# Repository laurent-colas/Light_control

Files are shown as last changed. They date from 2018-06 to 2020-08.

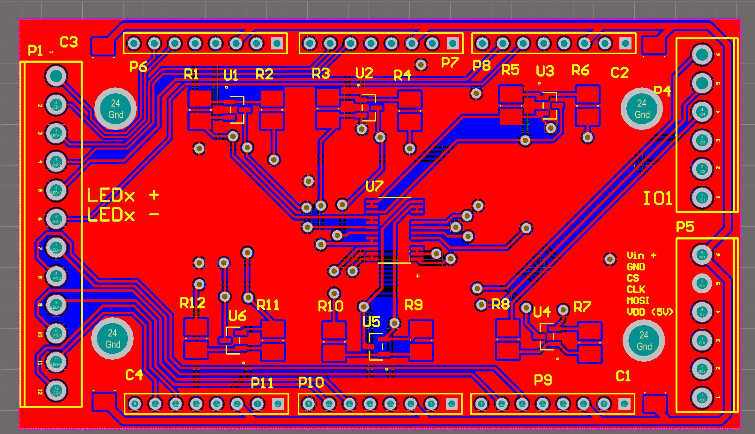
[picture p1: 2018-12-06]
CAD/LED driver buckpuck/Lumiere_ctrl_altiumV3/Img_pcb_annote.JPG

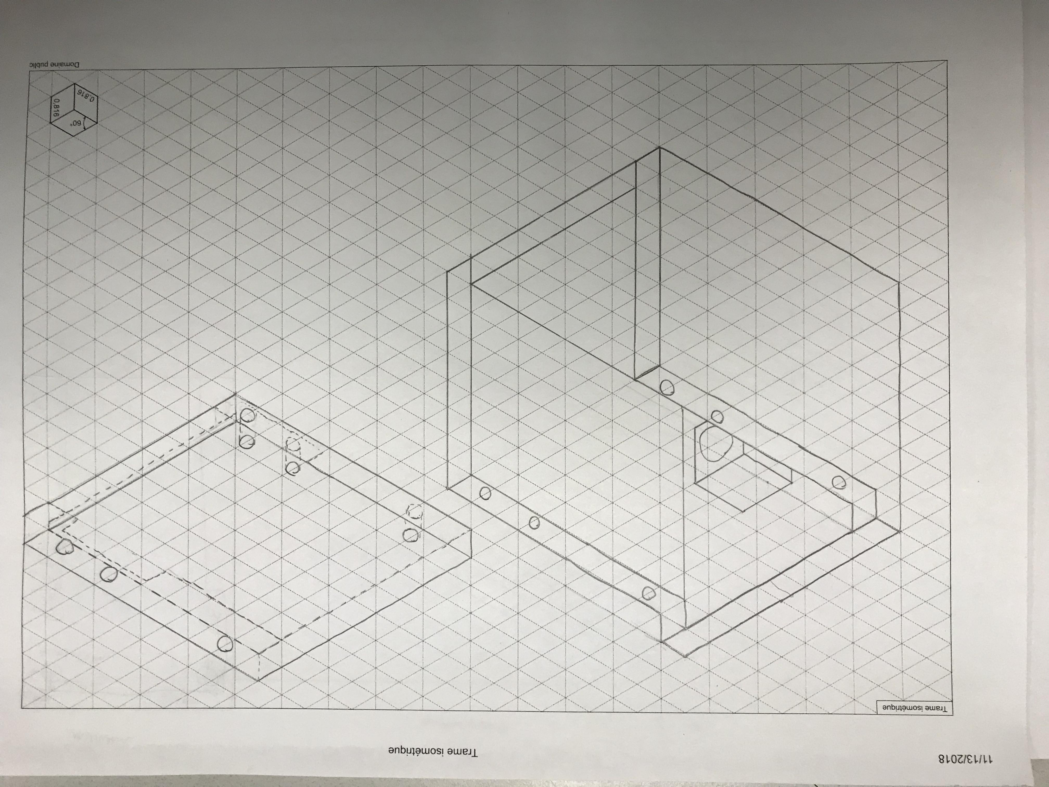
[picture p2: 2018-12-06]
CAD/Motion Detector/Detector Case/Detector V2/ISO_boitier.jpg

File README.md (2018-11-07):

# Light_control
Flask application for controlling lights in my house. 
This includes ESP8266 and ESP32 firmware for motion detectors, On-Off switches, On-Off Buttons. It also includes flask application to physically control light state / brightness with a 16 channel pwm controller, create macros to bundle rooms together and control these rooms with a simple click and check state online of every light.

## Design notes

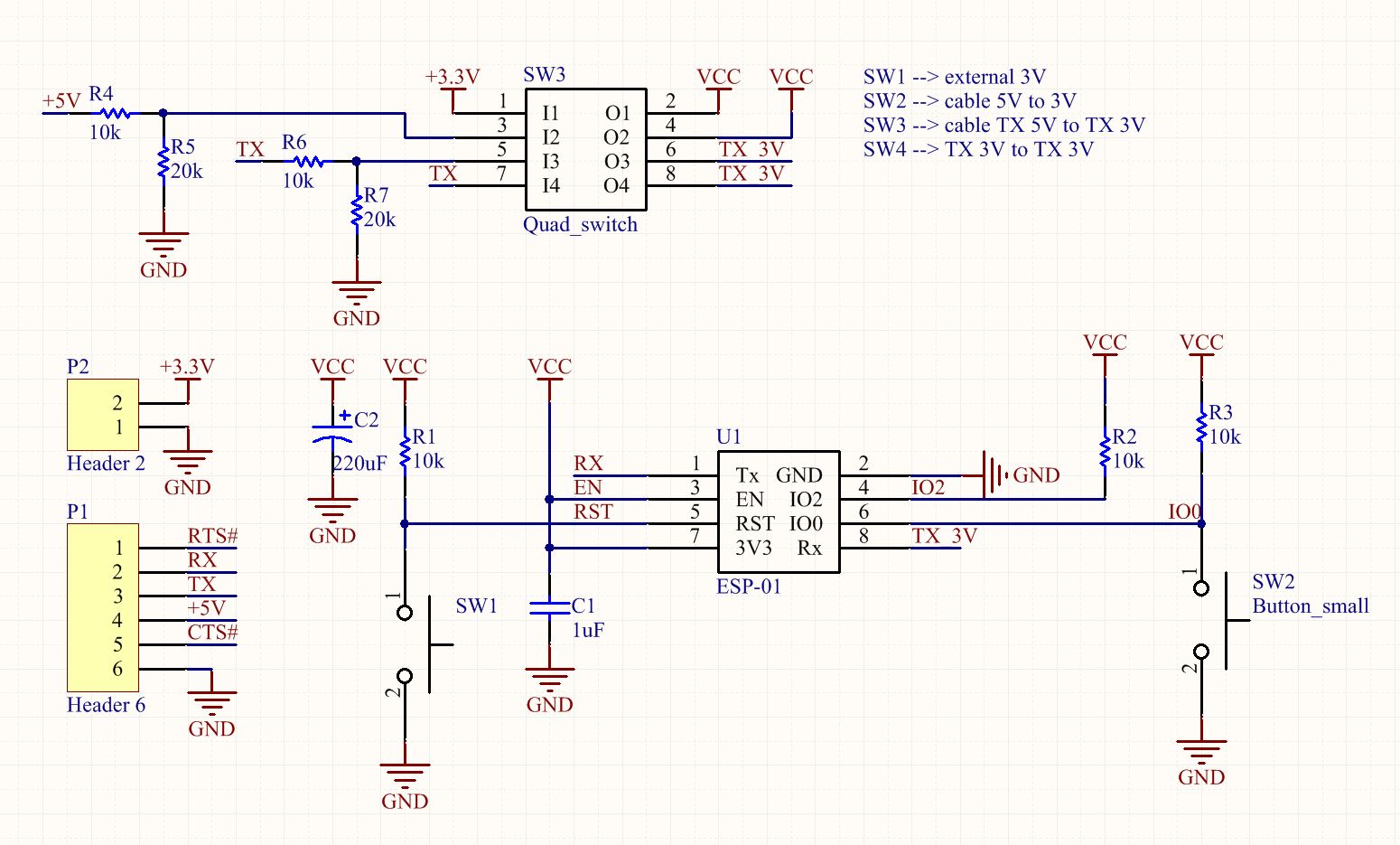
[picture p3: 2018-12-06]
CAD/Motion Detector/MotionDetectorV2/Images/Flashing_Circuit_Schematic_V2.jpg

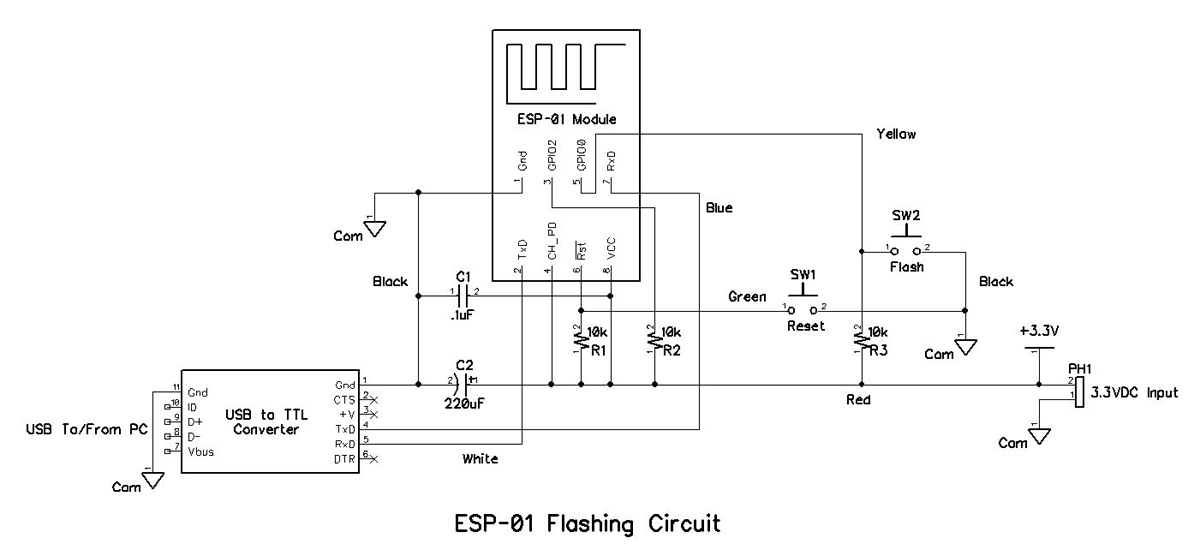
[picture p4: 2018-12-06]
CAD/Motion Detector/MotionDetectorV2/Images/Flashing_Circuit_Schematic.jpg

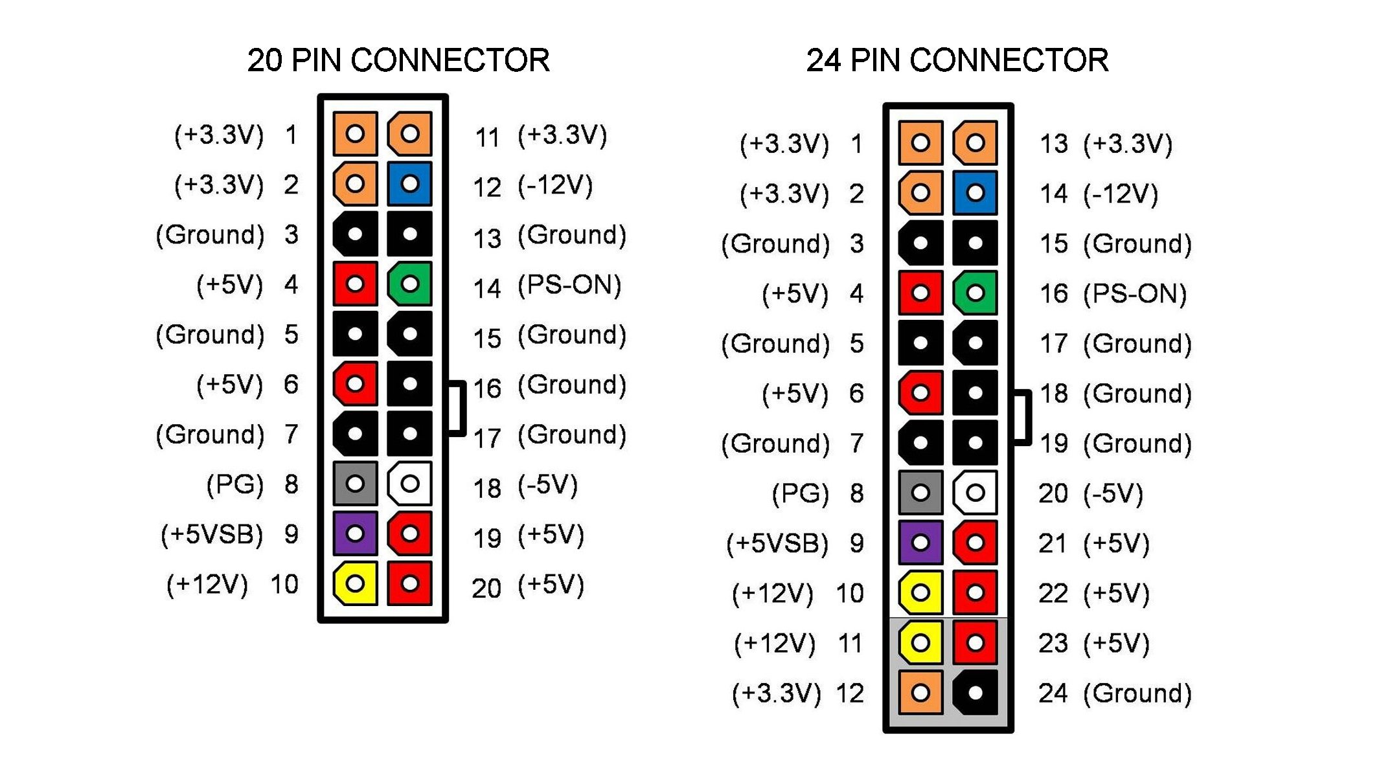
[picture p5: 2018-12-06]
Documentation/pinout_PSU.jpg

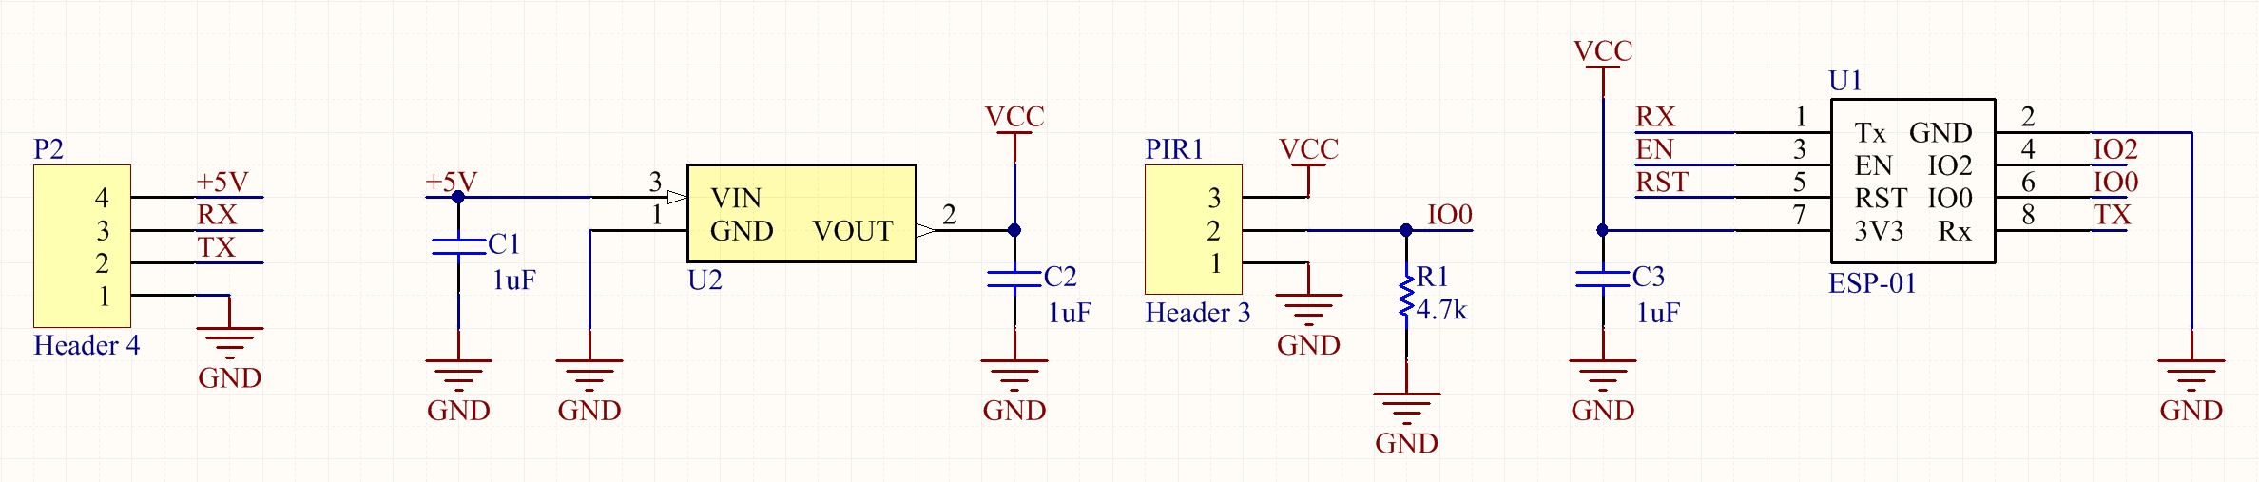
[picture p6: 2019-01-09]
CAD/Motion Detector/MotionDetectorV2/Schematic_MotionDetectV1.JPG

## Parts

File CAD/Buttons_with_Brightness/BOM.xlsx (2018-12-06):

Index | Quantity | Part Number | Manufacturer Part Number | Description | Customer Reference | Available | Backorder | Unit Price | Extended Price CAD
2 | 1 | P470ACT-ND | ERJ-6GEYJ471V | RES SMD 470 OHM 5% 1/8W 0805 |  | 1 | 0 | 0.15 | 0.15
4 | 1 | 401-1978-ND | D6R90 F1 LFS | SWITCH PUSH SPST-NO 0.1A 32V |  | 1 | 0 | 1.36 | 1.36
9 | 1 | 987-1277-ND | P090S-14T20BR10K | POT 10K OHM 1/32W PLASTIC LINEAR |  | 1 | 0 | 1.02 | 1.02
10 | 1 | 987-1276-ND | P090S-04F20BR10K | POT 10K OHM 1/32W PLASTIC LINEAR |  | 1 | 0 | 1.02 | 1.02
11 | 1 | 226-4092-ND | OEJL-50-4-7 | KNOB KNURLED 0.236" METAL |  | 1 | 0 | 9.71 | 9.71
15 | 1 | P10KDACT-ND | ERA-6AEB103V | RES SMD 10K OHM 0.1% 1/8W 0805 |  | 1 | 0 | 0.54 | 0.54
16 | 1 | PTA2043-2015DPB103-ND | PTA2043-2015DPB103 | SLIDE POT 10K OHM 0.1W TOP 20MM |  | 1 | 0 | 1.83 | 1.83

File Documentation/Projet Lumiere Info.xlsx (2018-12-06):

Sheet: Naming Shematic
IO # | Name | Nom de la zone |  | Nombre de LED par zone | Endroit dimable | Sur page principale | Pre set 1 | Pre set 2
22 | RELAY1 | Entrée |  | 4 |  | x | x
23 | RELAY2 | Garde Robe entrée |  | 2 |  | x | x
24 | RELAY3 | Corridor |  | 4 | x | x | x
25 | RELAY4 | Salon |  | 3 | x | x | x
26 | RELAY5 | Cuisine | Drop Down | 4 | x | x | x
27 | RELAY6 | Comptoir telephone cuisine |  | 2 |  |  | x
28 | RELAY7 | Comptoir lavabos cuisine |  | 2 |  |  | x
29 | RELAY8 | Salle à manger |  | 3 | x
30 | RELAY9 | Fond salle à manger |  | 3 | x
31 | RELAY10 | Salle d'ordinateur |  | 1 |  |  | x
32 | RELAY11 | Salle de Bain 1er étage |  | 2 | x |  | x
33 | RELAY12 | Chambre d'invité Télé |  | 2
34 | RELAY13 | Chambre d'invité Lit |  | 4 | x
35 | RELAY14 | Chambre d'invité garde-Robe |  | 2
36 | RELAY15 | Chambre d'invité imprimante |  | 1
37 | RELAY16 | Bibliothèque |  | 3
38 | RELAY17 | Escalier Sous-sol |  | 3
39 | RELAY18 | Plafond escalier sous-sol |  | 3
40 | RELAY19 | Sous-Sol |  | 6 | x
41 | RELAY20 | Fond sous-sol |  | 3
42 | RELAY21 | Chambre Laurent |  | 3 | x
43 | RELAY22 | Garde Robe Laurent |  | 1
44 | RELAY23 | Chambre Anne-Sophie |  | 2 | x
45 | RELAY24 | Walk-in Anne-Sophie |  | 1
46 | RELAY25 | Rangement Anne-Sophie |  | 2
47 | RELAY26 | Salle de lavage |  | 2
48 | RELAY27 | Salle de Bain 2ième étage |  | 3 | x
49 | RELAY28 | Statue |  | 1
50 | RELAY29 | Chambre parents lits |  | 2 | x
51 | RELAY30 | Chambre parents fenêtre |  | 2 | x
52 | RELAY31 | Walk-in parents |  | 2
53 | RELAY32 | Rangement parents |  | 2
 |  | Nombre de DEL total |  | 80 | 13

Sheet: RC
IO # | Name | Nom de la zone | Nombre de LED par zone | Endroit dimable | Sur page principale | Pre set 1 | Pre set 2
22 | RELAY1 | Entrée | 4
23 | RELAY2 | Garde Robe entrée | 2
24 | RELAY3 | Corridor | 4
25 | RELAY4 | Salon | 3
26 | RELAY5 | Cuisine | 6
27 | RELAY6 | Comptoir telephone cuisine | 1
28 | RELAY7 | Comptoir lavabos cuisine | 4
29 | RELAY8 | Salle à manger | 3
30 | RELAY9 | Fond salle à manger | 2
31 | RELAY10 | Salle d'ordinateur | 1
32 | RELAY11 | Salle de Bain 1er étage | 6
33 | RELAY12 | Chambre d'invité Télé | 2
34 | RELAY13 | Chambre d'invité Lit | 4
35 | RELAY14 | Chambre d'invité garde-Robe | 2
36 | RELAY15 | Chambre d'invité imprimante | 1
37 | RELAY16 | Bibliothèque | 2

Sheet: LED Driver board specs
Pour | 1
 | Index | Quantity per board | Part Number | Manufacturer Part Number | Description | Unit Price | Extended Price per board
 | 1 | 6 | MMBT3906LT1GOSCT-ND | MMBT3906LT1G | TRANS PNP 40V 0.2A SOT23 | 0.146 | 0.876
 | 2 | 12 | YAG5090CT-ND | RT1206BRD075KL | RES SMD 5K OHM 0.1% 1/4W 1206 | 0.3012 | 3.6144
 | 3 | 4 | 1276-1053-1-ND | CL31C101JBCNNNC | CAP CER 100PF 50V C0G/NP0 1206 | 0.15 | 0.6
 | 4 | 1 | AD5206BRUZ10-RL7CT-ND | AD5206BRUZ10-RL7 | IC POT DGTL 6CH 256POS 24-TSSOP | 8.54 | 8.54
 | 5 | 12 | 277-1721-ND | 1984617 | CONN TERM BLOCK T/H 2POS 3.5MM | 0.565 | 6.78
 | 6 | 6 | S7041-ND | PPPC081LFBN-RC | CONN HEADER FEMALE 8POS .1" GOLD | 0.863 | 5.178
 |  |  |  |  |  | Subtotal | 25.5884
Pour | 6
 |  | Quantity | Unfinished boards | Description | Manufacturer Part Number | Total | Extended Price
 |  | 36 | 0 | TRANS PNP 40V 0.2A SOT23 | MMBT3906LT1G | 36 | 5.256
 |  | 72 | 0 | RES SMD 5K OHM 0.1% 1/4W 1206 | RT1206BRD075KL | 72 | 21.6864
 |  | 24 | 8 | CAP CER 100PF 50V C0G/NP0 1206 | CL31C101JBCNNNC | 32 | 4.8
 |  | 6 | 4 | IC POT DGTL 6CH 256POS 24-TSSOP | AD5206BRUZ10-RL7 | 10 | 85.4
 |  | 72 | 42 | CONN TERM BLOCK T/H 2POS 3.5MM | 1984617 | 114 | 64.41
 |  | 36 | 24 | CONN HEADER FEMALE 8POS .1" GOLD | PPPC081LFBN-RC | 60 | 51.78
 |  |  |  |  |  | Subtotal | 233.3324

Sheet: Orders
Supplier | Index | Quantity | Part Number | Manufacturer Part Number | Description | Unit Price | Extended Price | Shipping
Digikey | 1 | 2 | 976-1396-ND | BXRC-30E1000-D-73 | LED COB VERO 10 3000K STARBOARD | 4.32 $ | 8.64 $ | 0.00 $
 | 2 | 1 | 976-1254-ND | BXRC-30E2000-C-23 | LED ARRAY 2000LM WARM WHITE COB | 7.83 $ | 7.83 $
 | 3 | 1 | 976-1242-ND | BXRC-27E4000-F-23 | LED ARRAY 4000LM WARM WHITE COB | 14.35 $ | 14.35 $
 | 4 | 100 | YAG5090CT-ND | RT1206BRD075KL | RES SMD 5K OHM 0.1% 1/4W 1206 | 0.29 $ | 29.42 $
 | 5 | 100 | 1276-1053-1-ND | CL31C101JBCNNNC | CAP CER 100PF 50V C0G/NP0 1206 | 0.07 $ | 6.91 $
 | 6 | 60 | S7041-ND | PPPC081LFBN-RC | CONN HEADER FEMALE 8POS .1" GOLD | 0.84 $ | 50.58 $
 | 7 | 40 | 277-1724-ND | 1984659 | CONN TERM BLOCK T/H 6POS 3.5MM | 1.64 $ | 65.76 $
 | 8 | 100 | MMBTA92LT1GOSCT-ND | MMBTA92LT1G | TRANS PNP 300V 0.5A SOT23 | 0.14 $ | 13.93 $
 | 9 | 40 | MMBT3906LT1GOSCT-ND | MMBT3906LT1G | TRANS PNP 40V 0.2A SOT23 | 0.15 $ | 5.84 $ | 0.00 $
 | 10 | 100 | YAG5090CT-ND | RT1206BRD075KL | RES SMD 5K OHM 0.1% 1/4W 1206 | 0.30 $ | 30.12 $
 | 11 | 10 | 1276-1053-1-ND | CL31C101JBCNNNC | CAP CER 100PF 50V C0G/NP0 1206 | 0.15 $ | 1.50 $
 | 12 | 6 | AD5206BRUZ10-RL7CT-ND | AD5206BRUZ10-RL7 | IC POT DGTL 6CH 256POS 24-TSSOP | 8.54 $ | 51.24 $
 | 13 | 10 | 277-1721-ND | 1984617 | CONN TERM BLOCK T/H 2POS 3.5MM | 0.56 $ | 5.65 $
 | 14 | 10 | 277-1578-ND | 1935174 | TERM BLOCK PCB 3POS 5.0MM GREEN | 0.72 $ | 7.23 $
 | 15 | 10 | 277-1581-ND | 1935200 | TERM BLOCK PCB 6POS 5.0MM GREEN | 1.46 $ | 14.57 $
 | 16 | 10 | 277-1587-ND | 1935268 | TERM BLOCK PCB 12POS 5.0MM GREEN | 2.78 $ | 27.77 $
 | 17 | 40 | S7041-ND | PPPC081LFBN-RC | CONN HEADER FEMALE 8POS .1" GOLD | 0.86 $ | 34.52 $
Amazon | 18 | 4 | LED-277 | B01CS5G8J6 | NEWSTYLE 24V 15A Dc Universal Regulated Switching Power Supply 360W | 33.98 $ | 135.92 $ | 21.52 $
 | 19 | 2 | 101-70-103 | B0057OC66U | SainSmart 16-Channel Relay Module | 23.99 $ | 47.98 $ | 0.00 $
 | 20 | 1 | NCUIABVYA0225 | B01CCF6V3A | CanaKit Raspberry Pi 3 Complete Starter Kit - 32 GB Edition | 99.99 $ | 99.99 $
McMaster-Carr | 21 | 10 | 98952A108 |  | Aluminum Male-Female Threaded Hex Standoff, 4.5mm Hex, 10mm Long, M3 x 0.50 mm Thread | 1.35 $ | 13.50 $ | 12.89 $
 | 22 | 10 | 98952A102 |  | Aluminum Male-Female Threaded Hex Standoff, 4.5mm Hex, 5mm Long, M3 x 0.50 mm | 1.29 $ | 12.90 $
 | 23 | 10 | 98952A112 |  | Aluminum Male-Female Threaded Hex Standoff, 4.5mm Hex, 14mm Long, M3 x 0.50 mm | 1.40 $ | 14.00 $
 | 24 | 10 | 98952A118 |  | Aluminum Male-Female Threaded Hex Standoff, 4.5mm Hex, 20mm Long, M3 x 0.50 mm | 1.47 $ | 14.70 $
 | 25 | 1 | 92000A118 |  | Passivated 18-8 Stainless Steel Pan Head Phillips Screws, M3 x 0.5mm Thread, 8mm Long | 4.16 $ | 4.16 $
 | 26 | 1 | 92000A114 |  | Passivated 18-8 Stainless Steel Pan Head Phillips Screws, M3 x 0.5mm Thread, 5mm Long | 4.12 $ | 4.12 $
 | 27 | 20 | 95947A006 |  | Aluminum Female Threaded Hex Standoff, 4.5mm Hex, 10mm Long, M3 x 0.50 mm Thread | 0.45 $ | 9.00 $
 | 28 | 1 | 93187A100 |  | Brass Thin Hex Nut, M3 x 0.5 mm Thread | 7.59 $ | 7.59 $
 | 29 | 5 |  |  | 300V AC/300V DC Terminal Block, Twelve 20A | 5.45 $ | 27.25 $ | 19.65 $
 | 30 | 5 |  |  | Cover for 12 Circuit 3/8" Center-to-Center 300V AC/300V DC Terminal Block | 3.35 $ | 16.75 $
 | 31 | 2 |  |  | Spade Terminals, Nylon Insulated, Flanged, for 22-18 Gauge & Number 6 Screw, Packs of 50 | 12.05 $ | 24.10 $
 | 32 | 2 |  |  | Spade Terminals, Nylon Insulated, Flanged, for 16-14 Gauge & Number 6 Screw, Packs of 50 | 12.24 $ | 24.48 $
Subtotal | 832.30 $ |  |  |  |  |  |  | 54.06 $
Total | 886.36 $

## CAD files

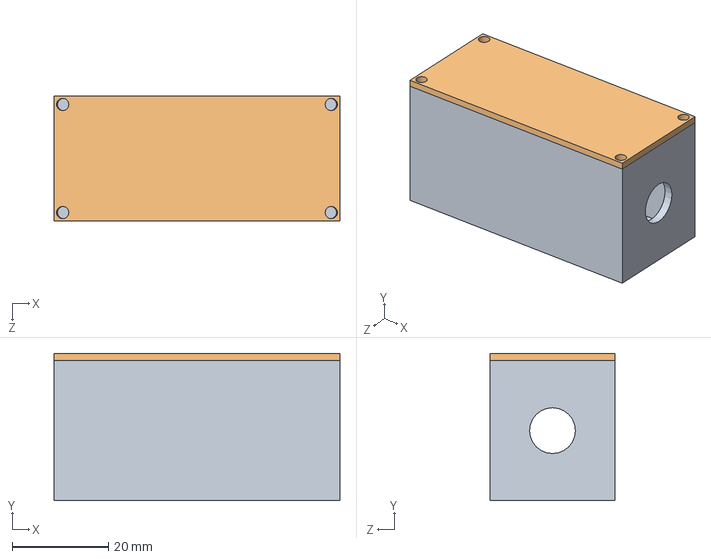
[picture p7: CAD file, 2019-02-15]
CAD/Motion Detector/Detector Case/Detector V2/AssemblyV2.SLDASM
59.3 x 30.5 x 26.0 mm
BDv2
CapuchonV2

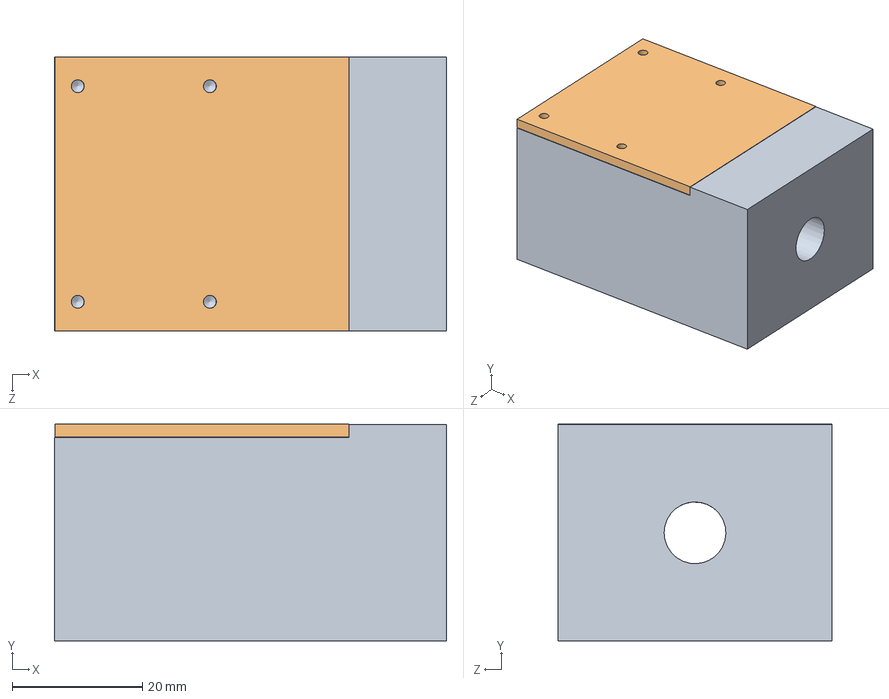
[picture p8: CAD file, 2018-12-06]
CAD/Motion Detector/Detector Case/Detector V2/Assembly detecteur.SLDASM
60.3 x 33.3 x 42.1 mm
boite detecteur
capuchon detecteur

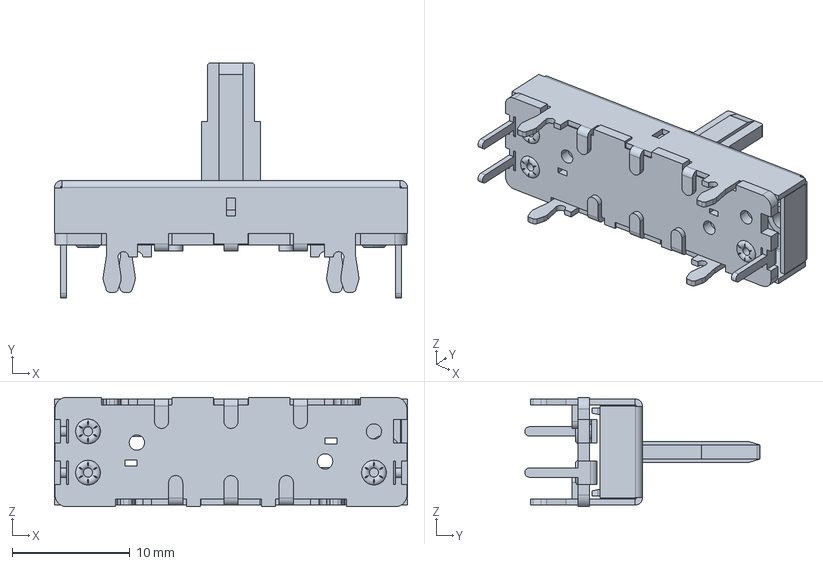
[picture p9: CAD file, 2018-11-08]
CAD/Buttons_with_Brightness/Documentation/Potentiometers/PTA1543-2010CIB103.stp
30.0 x 20.0 x 9.30 mm

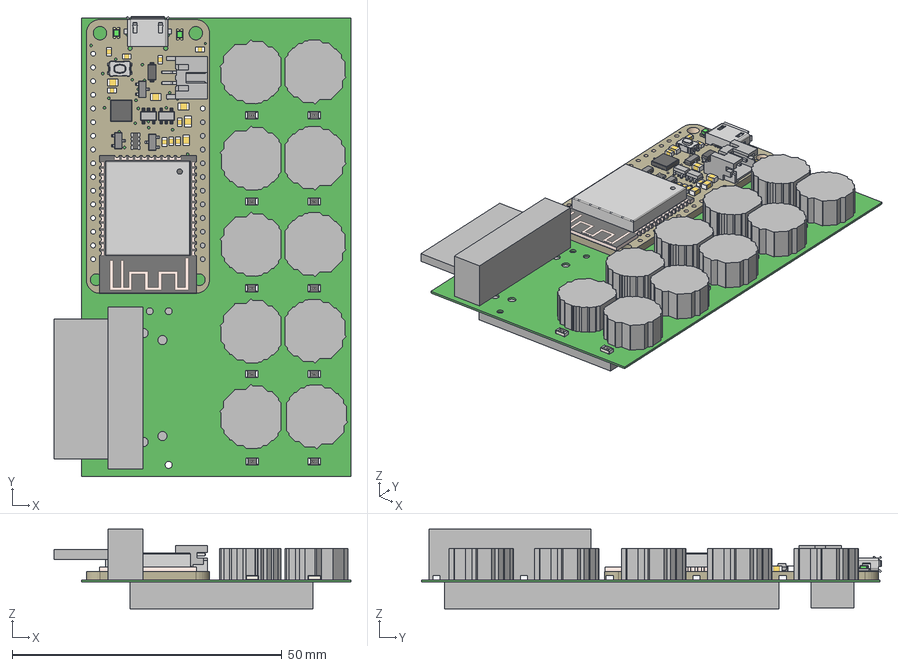
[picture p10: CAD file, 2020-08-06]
CAD/Buttons_with_Brightness/remote_control_light/remote_control_light.step
55.1 x 85.3 x 14.8 mm
Extruded x 14
res0805 x 10
Board
0805-NO x 5
0603-NO x 9
SOT23-5 x 2
SOD-123
JSTPH2
CHIPLED_0805_NOOUTLINE x 2
BTN_KMR2_4.6X2.8
QFN24_4MM_SMSC
4UCONN_20329_V2
SOT23-3 x 2
WROOM32_SKINNY
SOT23-R
RESPACK_4X0603

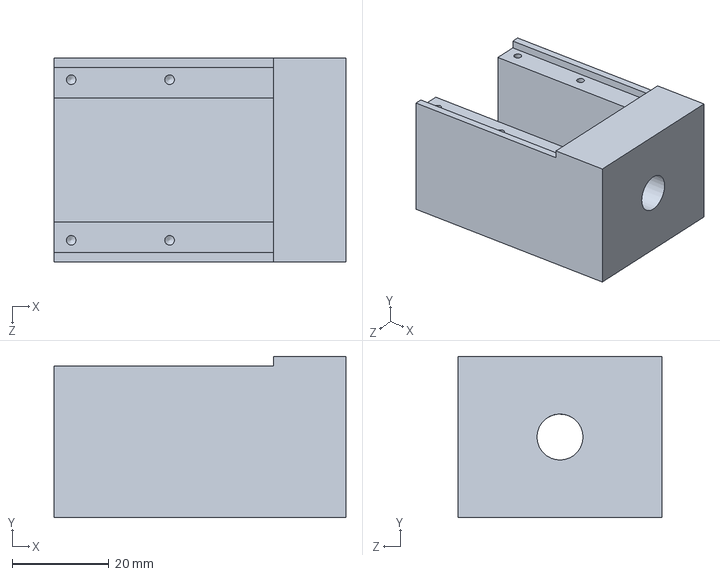
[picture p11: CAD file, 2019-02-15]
CAD/Motion Detector/Detector Case/Detector V2/Boite Detecteur V2.SLDPRT
60.3 x 33.3 x 42.1 mm

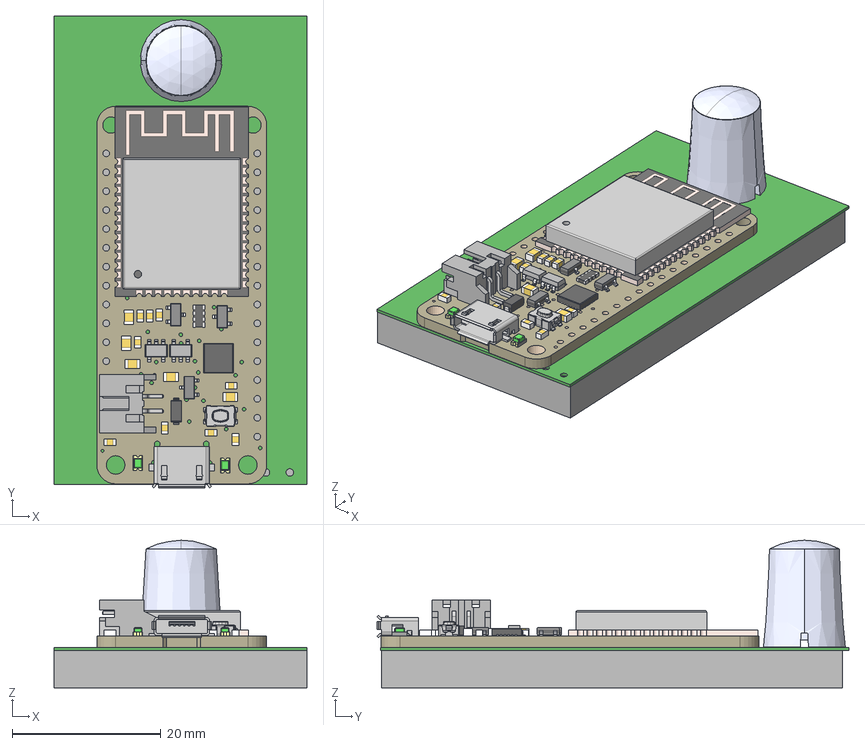
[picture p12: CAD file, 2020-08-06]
CAD/Motion Detector/Motion_detector_ESP32/Motion_detector_ESP32.step
34.0 x 63.5 x 19.9 mm
Extruded
EKM_StandardDetectionType
Board
0805-NO x 5
0603-NO x 9
SOT23-5 x 2
SOD-123
JSTPH2
CHIPLED_0805_NOOUTLINE x 2
BTN_KMR2_4.6X2.8
QFN24_4MM_SMSC
4UCONN_20329_V2
SOT23-3 x 2
WROOM32_SKINNY
SOT23-R
RESPACK_4X0603

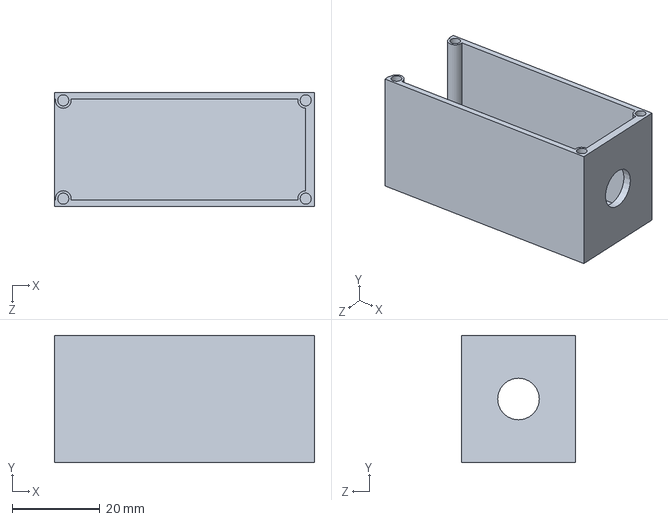
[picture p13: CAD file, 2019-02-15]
CAD/Motion Detector/Detector Case/Detector V2/BDv2.SLDPRT
59.3 x 29.0 x 26.0 mm

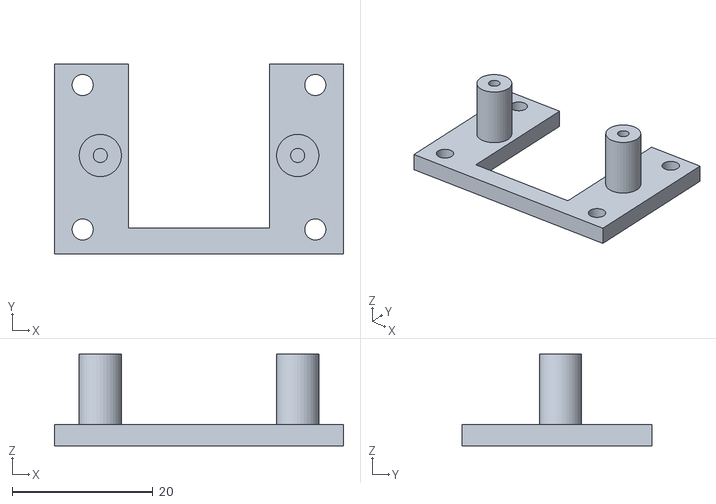
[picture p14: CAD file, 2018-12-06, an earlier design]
CAD/Motion Detector/Detector Case/Detector V1/Detecteur de lumiere interneV2.STL
41.0 x 27.0 x 13.0

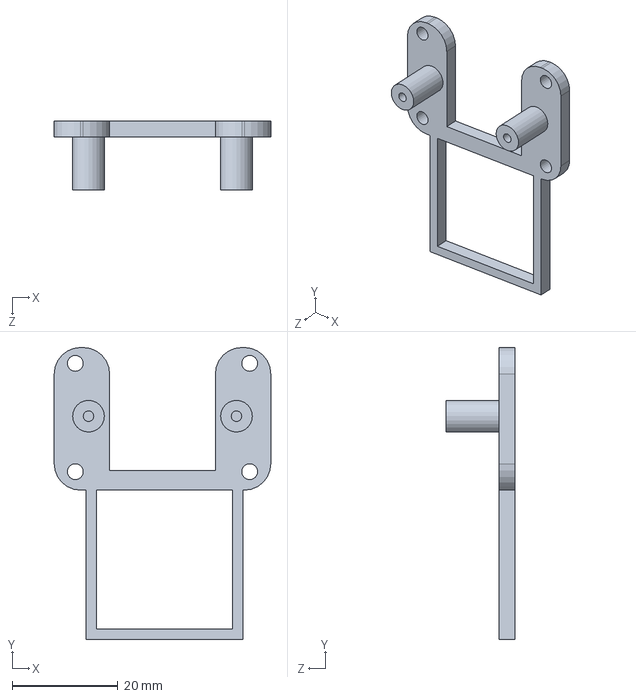
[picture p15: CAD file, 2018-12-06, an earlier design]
CAD/Motion Detector/Detector Case/Detector V1/Detecteur de lumiere interne.SLDPRT
41.0 x 55.3 x 13.0 mm

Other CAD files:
CAD/Motion Detector/Detector Case/Detector V1/Detecteur de lumiere interneV3.STL
CAD/Motion Detector/Detector Case/Detector V1/Detecteur de lumiere interne.STL

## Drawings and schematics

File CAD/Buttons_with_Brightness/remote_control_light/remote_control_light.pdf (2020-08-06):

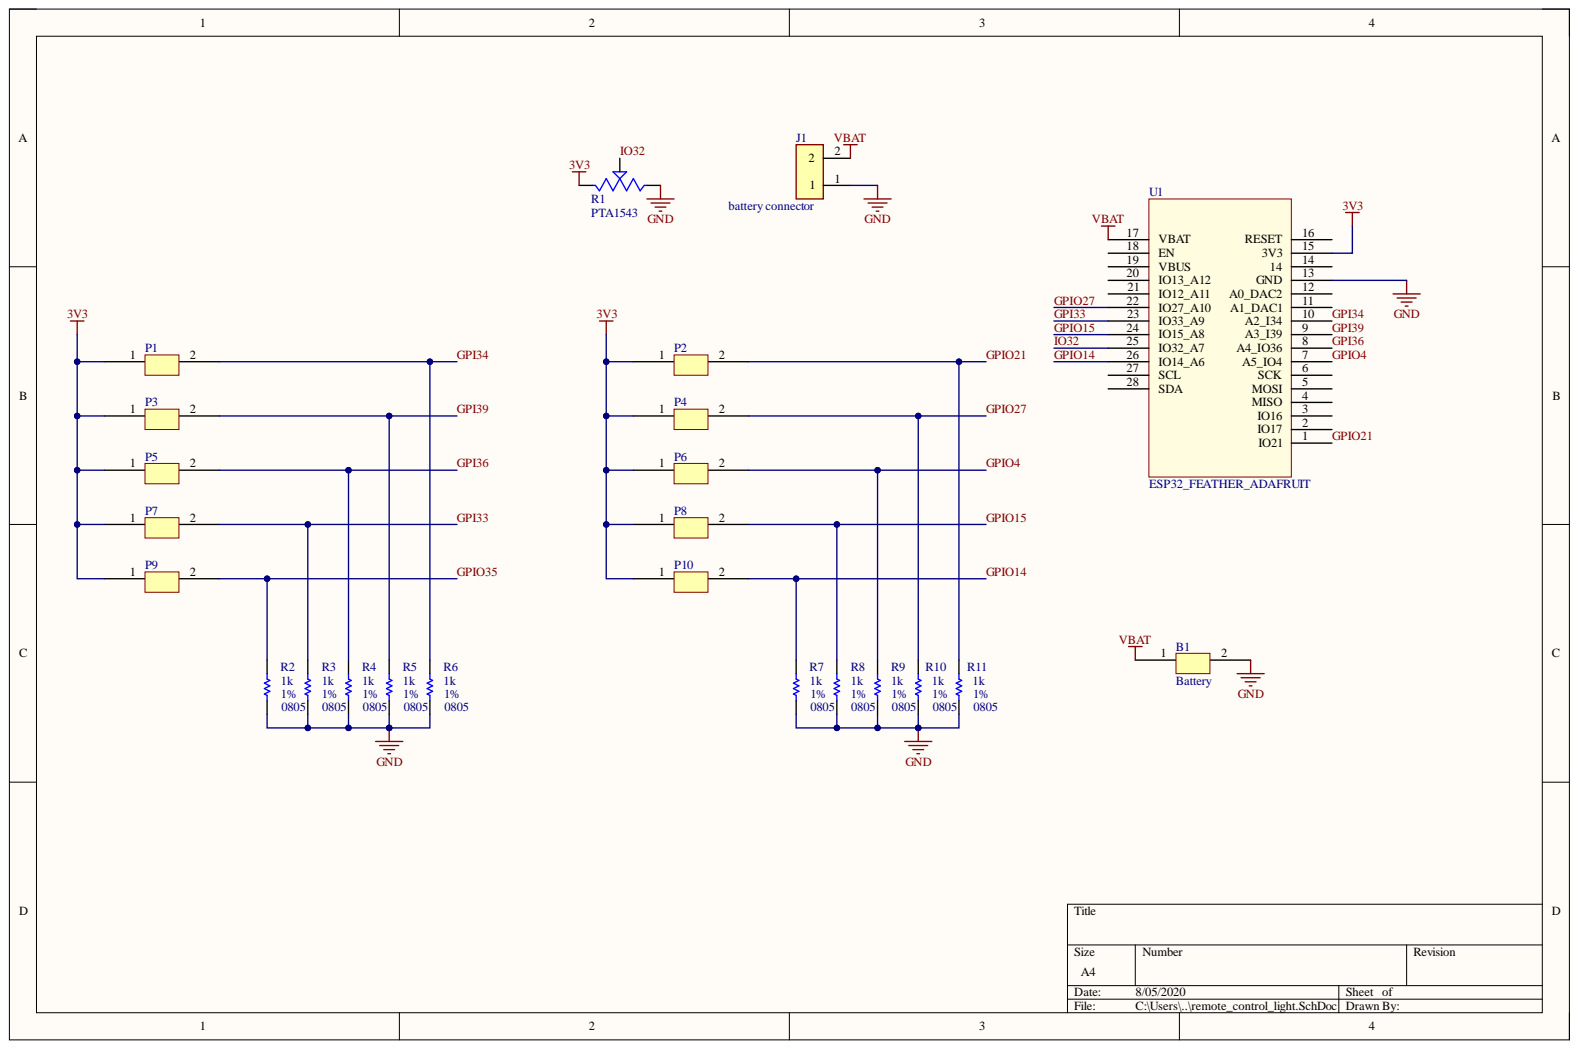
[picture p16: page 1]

Size A4 | Number | Revision

Date: 8/05/2020 | Sheet of
File: C:\Users\..\remote_control_light.SchDoc | Drawn By:

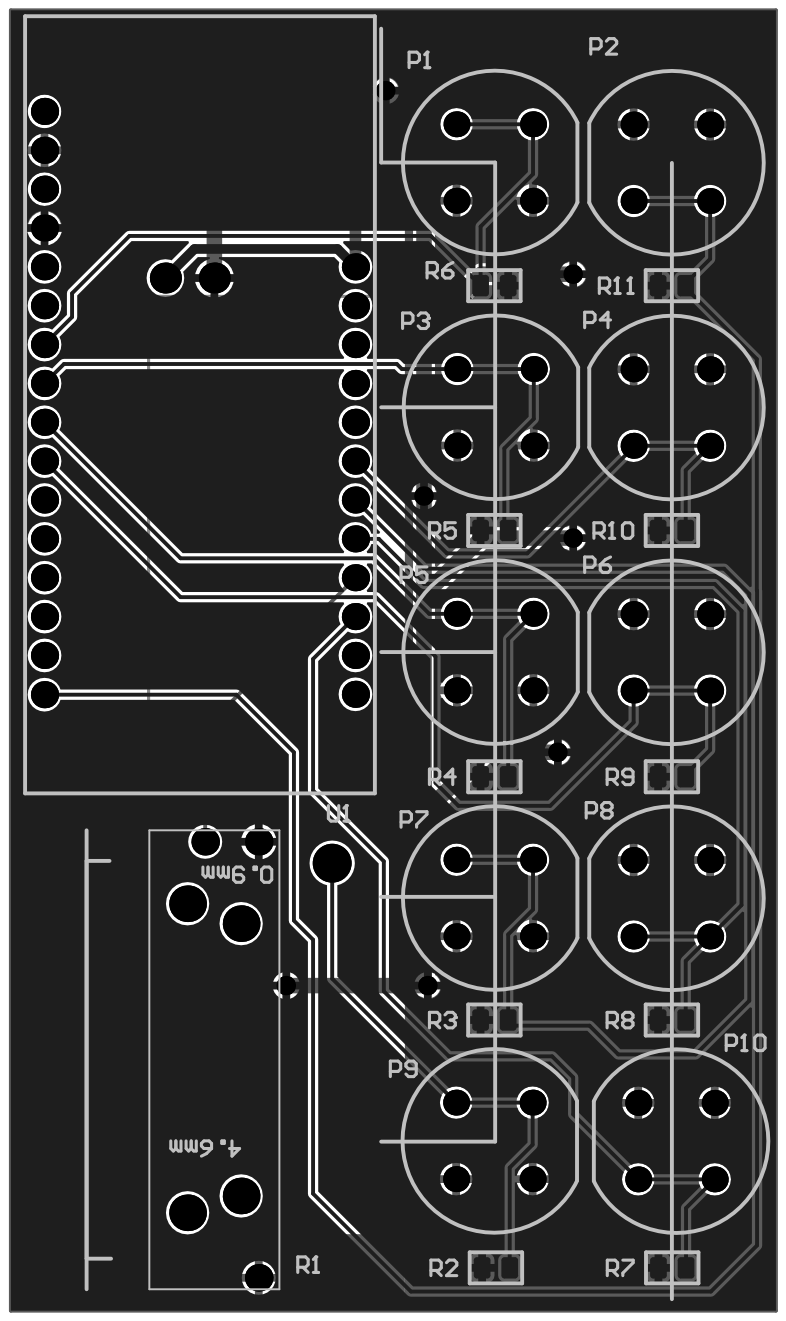
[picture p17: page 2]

Comment | Description | Designator | Footprint | LibRef | Quantity
Battery | | B1 | battery-3.7V-1200mAh | Battery | 1
battery connector | surface mount battery connector | J1 | Battery connector | CONN_BATT | 1
PUSH_BUTTON_D6F | | P1, P2, P3, P4, P5, P6, P7, P8, P9, P10 | PUSH_BUTTON_D6F | PUSH_BUTTON_D6F | 10
PTA1543 | 10 kOhms 0.05W, 1/20W Through Hole Slide Potentiometer Top Adjustment Type | R1 | POT PTA1543 | POT PTA1543 | 1
RES - 0805 | RES - 0805 | R2, R3, R4, R5, R6, R7, R8, R9, R10, R11 | RES_0805 | RES - 0805 | 10
ESP32_FEATHER_ADA FRUIT | | U1 | ESP32_FEATHER | ESP32_FEATHER_ADA FRUIT | 1

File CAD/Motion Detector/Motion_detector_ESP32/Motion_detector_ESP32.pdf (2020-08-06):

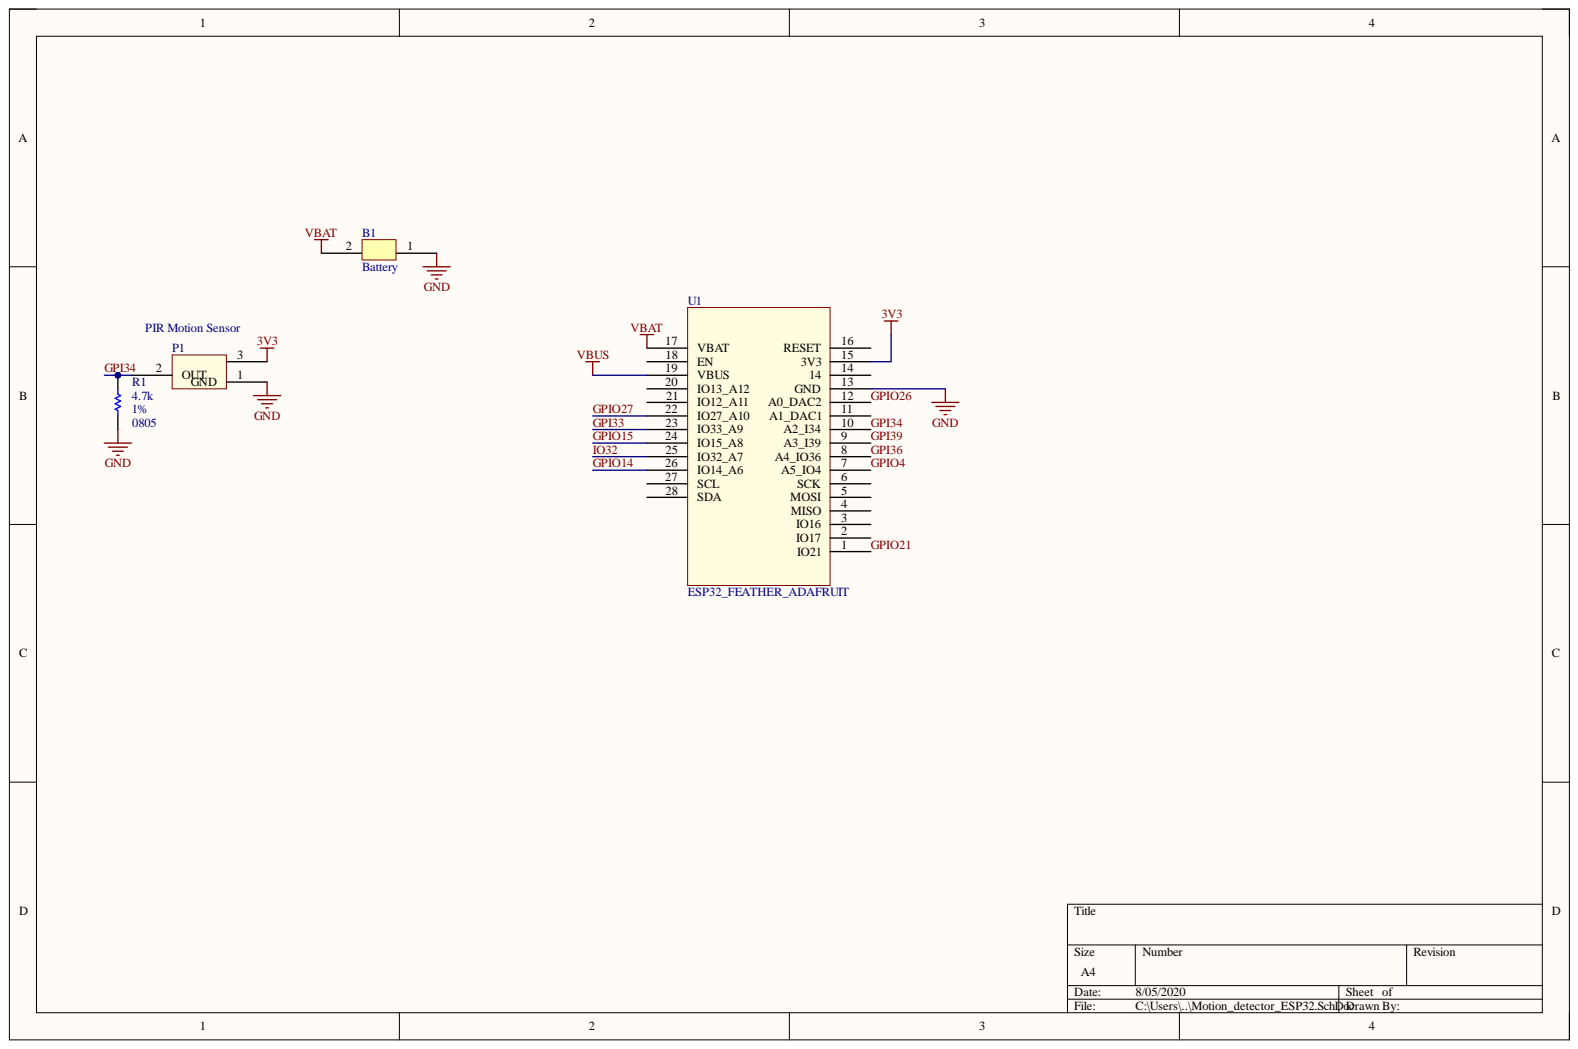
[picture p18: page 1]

Size A4 | Number | Revision

Date: 8/05/2020 | Sheet of
File: C:\Users\..\Motion_detector_ESP32.SchDoDr c awn By:

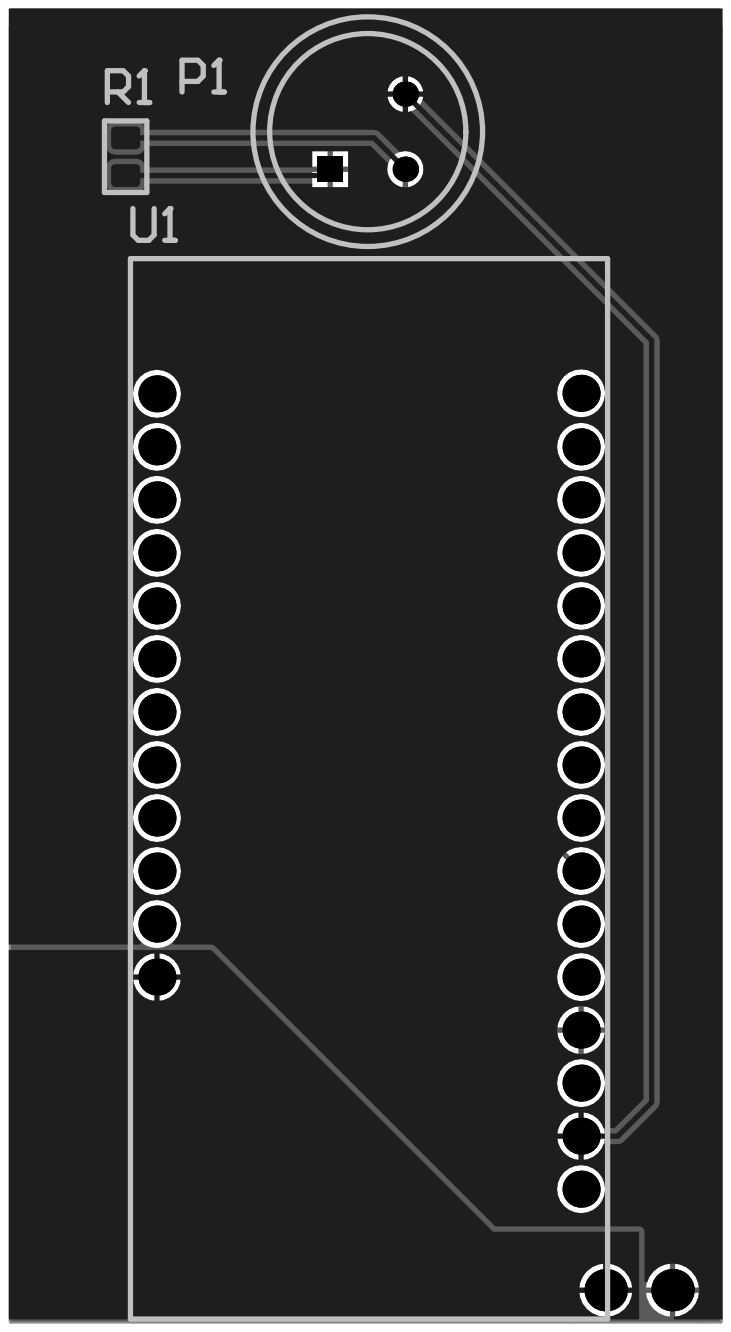
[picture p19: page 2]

Comment | Description | Designator | Footprint | LibRef | Quantity
Battery | | B1 | battery-3.7V-1200mAh | Battery | 1
PIR Motion Sensor | Sensor PIR (Passive Infrared) 197" (5m) 16.4' Polyethylene, White Lens | P1 | EKMB1301111K | PIR Motion Sensor | 1
RES - 0805 | RES - 0805 | R1 | RES_0805 | RES - 0805 | 1
ESP32_FEATHER_ADA FRUIT | | U1 | ESP32_FEATHER | ESP32_FEATHER_ADA FRUIT | 1

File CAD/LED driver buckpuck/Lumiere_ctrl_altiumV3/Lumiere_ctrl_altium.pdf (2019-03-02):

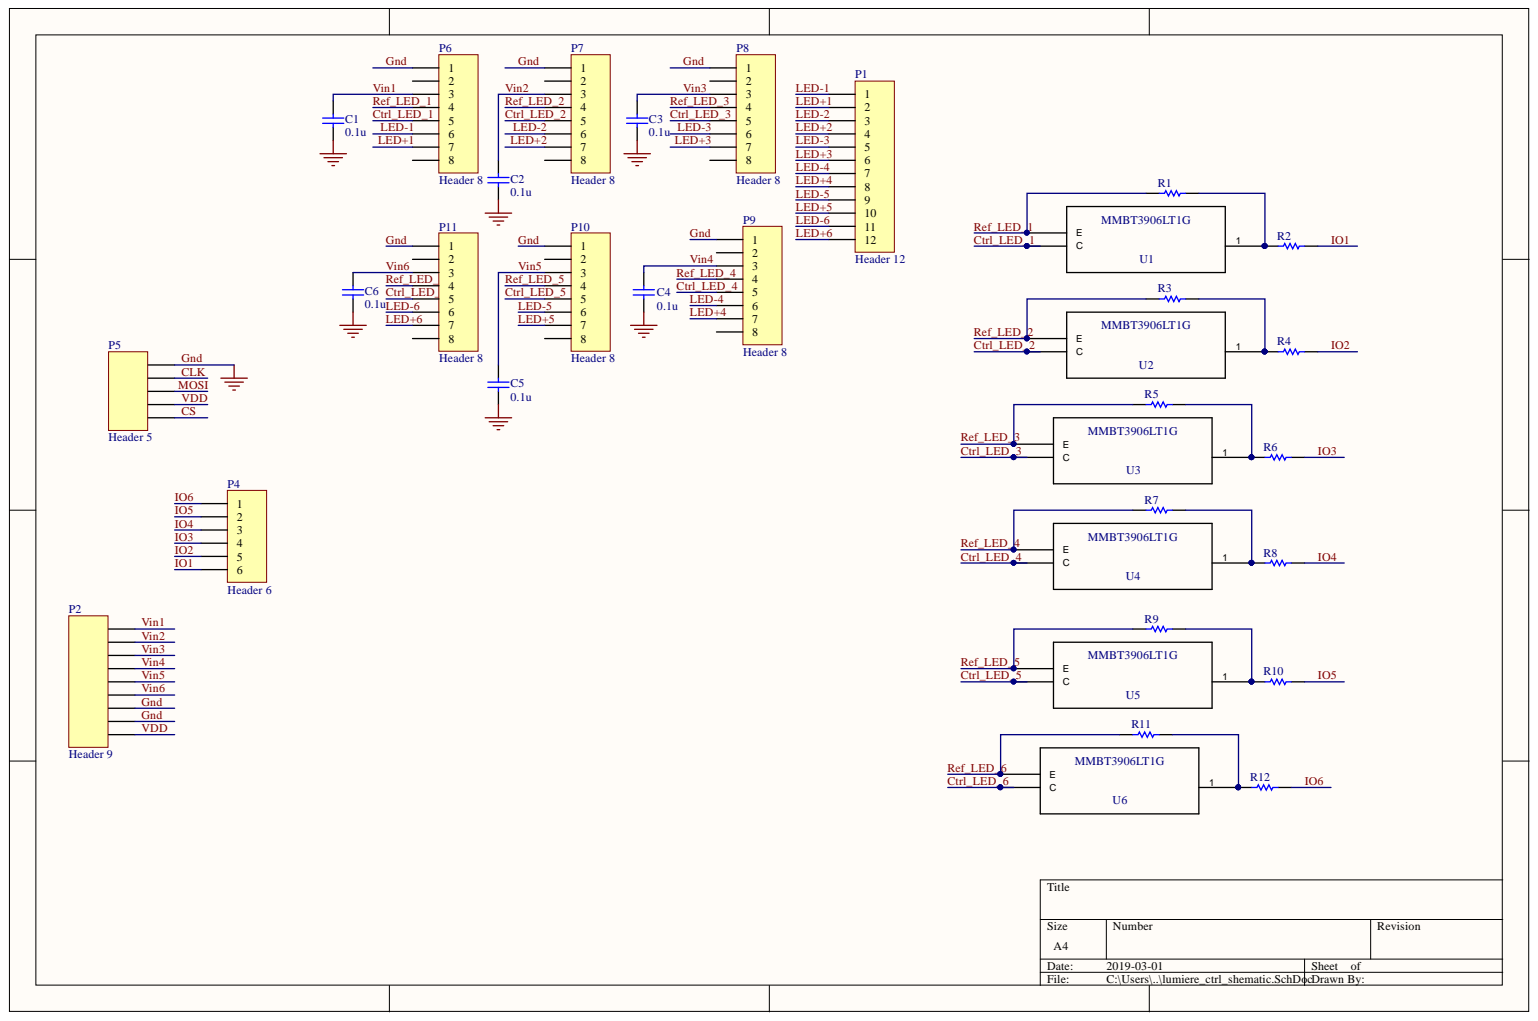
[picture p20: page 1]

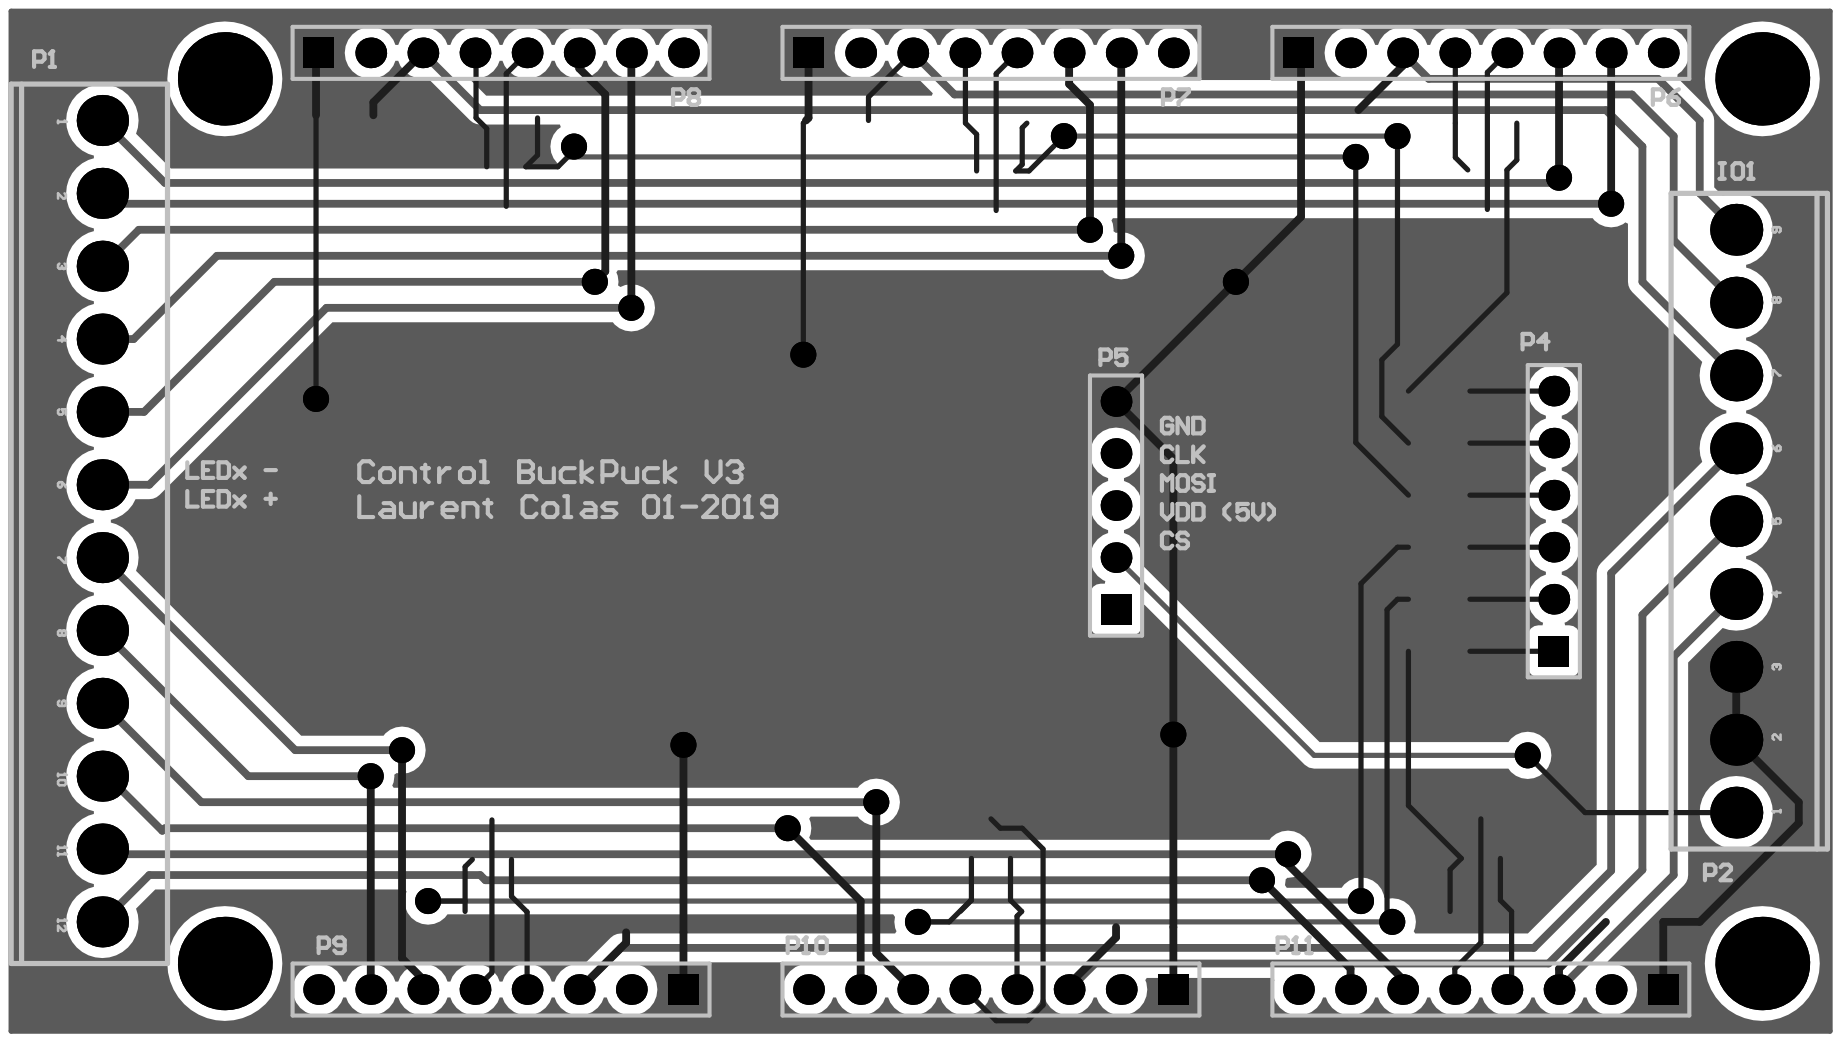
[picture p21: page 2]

Item#C# olumn Name Error:Manufact | #Column Name Error:Manufacturer No | Quantity | #Column Name Error:Note | Designator | Description | Footprint | Comment | LibRef
1 | | 6 | | C1, C2, C3, C4, C5, C6 | Capacitor | CC1206N | CapSMD | CapSMD
2 | | 1 | | P1 | Header, 12-Pin | Terminal block 12 pos | Header 12 | Header 12
3 | | 1 | | P2 | Header, 9-Pin | Terminal block 9 pos | Header 9 | Header 9
4 | | 1 | | P4 | Header, 6-Pin | HDR1X6 | Header 6 | Header 6
5 | | 1 | | P5 | Header, 5-Pin | HDR1X5 | Header 5 | Header 5
6 | | 6 | | P6, P7, P8, P9, P10, P11 | Header, 8-Pin | HDR1X8 | Header 8 | Header 8
7 | | 12 | | R1, R2, R3, R4, R5, R6, R7, R8, R9, R10, R11, R12 | | STA_RMCF1206 | ResSMD | ResSMD
8 | | 6 | | U1, U2, U3, U4, U5, U6 | | SOT-23 | MMBT3906LT1G | MMBT3906LT1G

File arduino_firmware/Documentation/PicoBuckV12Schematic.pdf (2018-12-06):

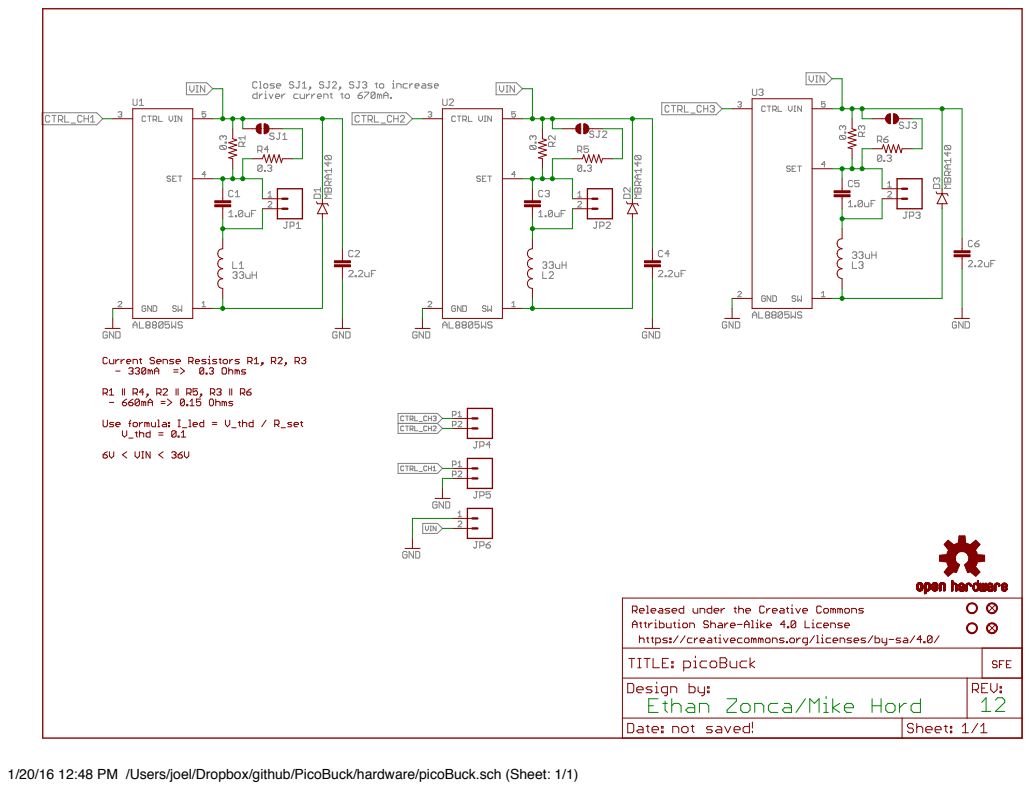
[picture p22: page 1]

1/20/16 12:48 PM /Users/joel/Dropbox/github/PicoBuck/hardware/picoBuck.sch (Sheet: 1/1)

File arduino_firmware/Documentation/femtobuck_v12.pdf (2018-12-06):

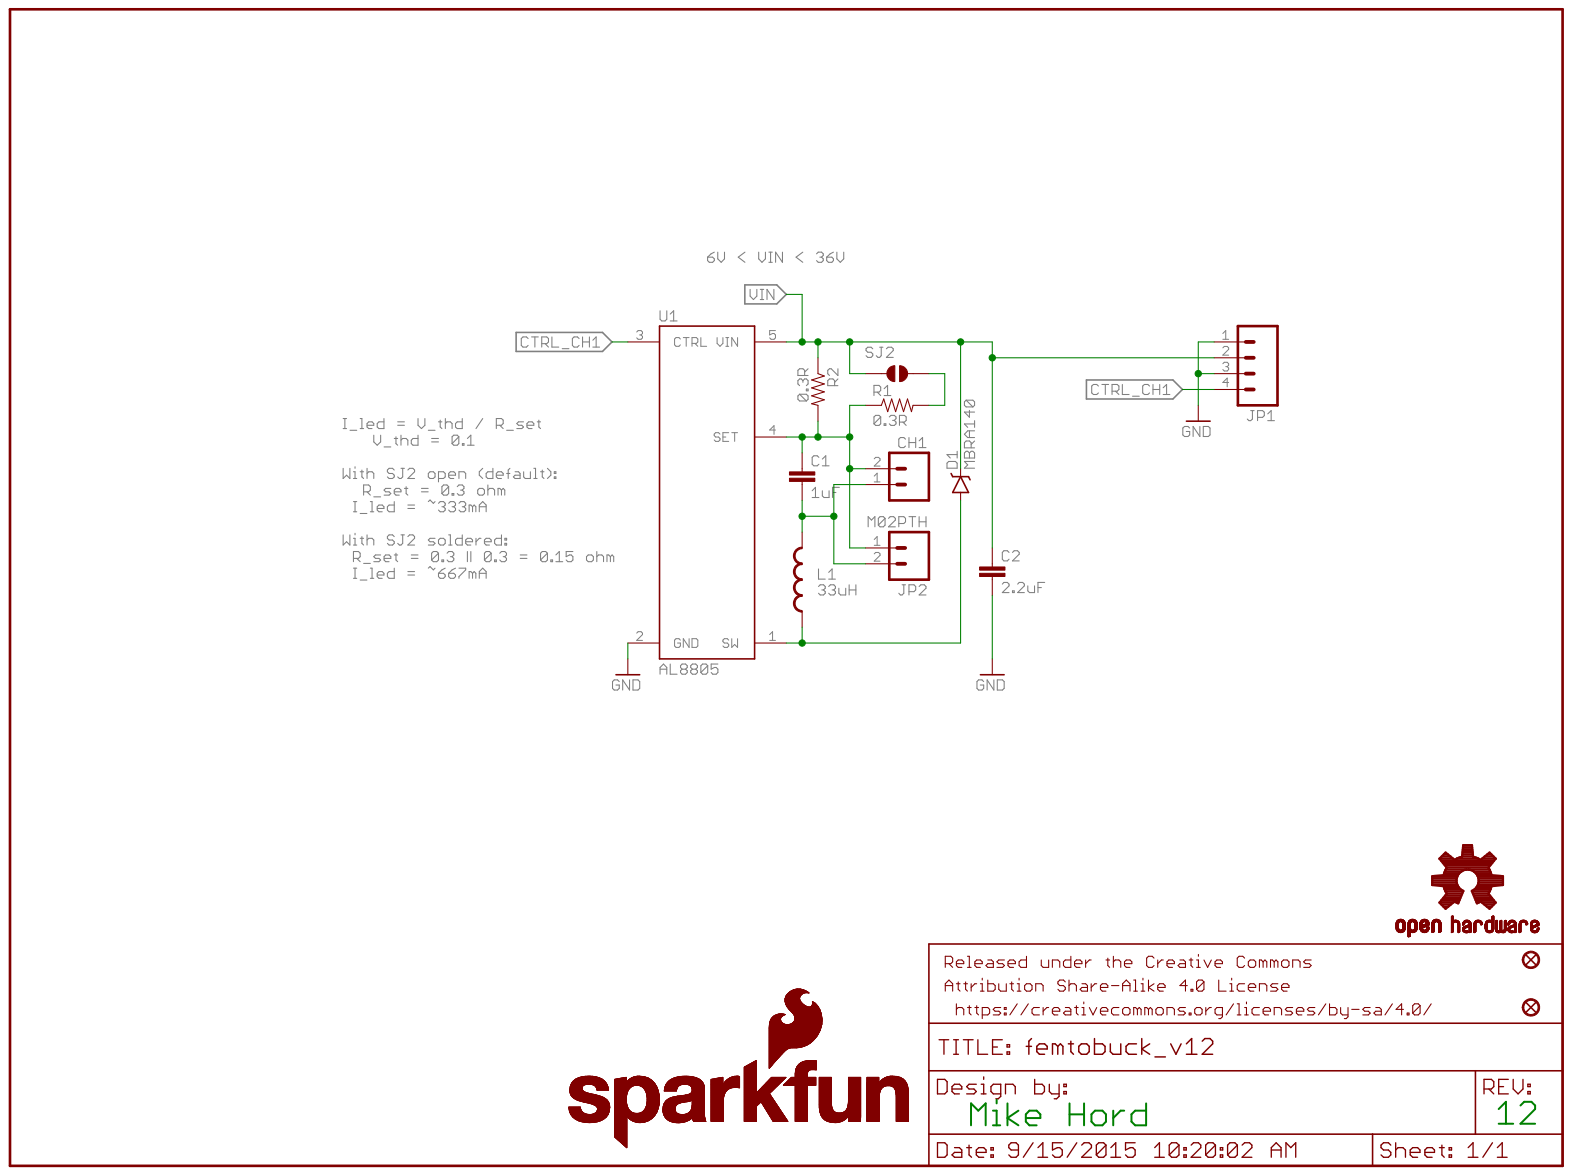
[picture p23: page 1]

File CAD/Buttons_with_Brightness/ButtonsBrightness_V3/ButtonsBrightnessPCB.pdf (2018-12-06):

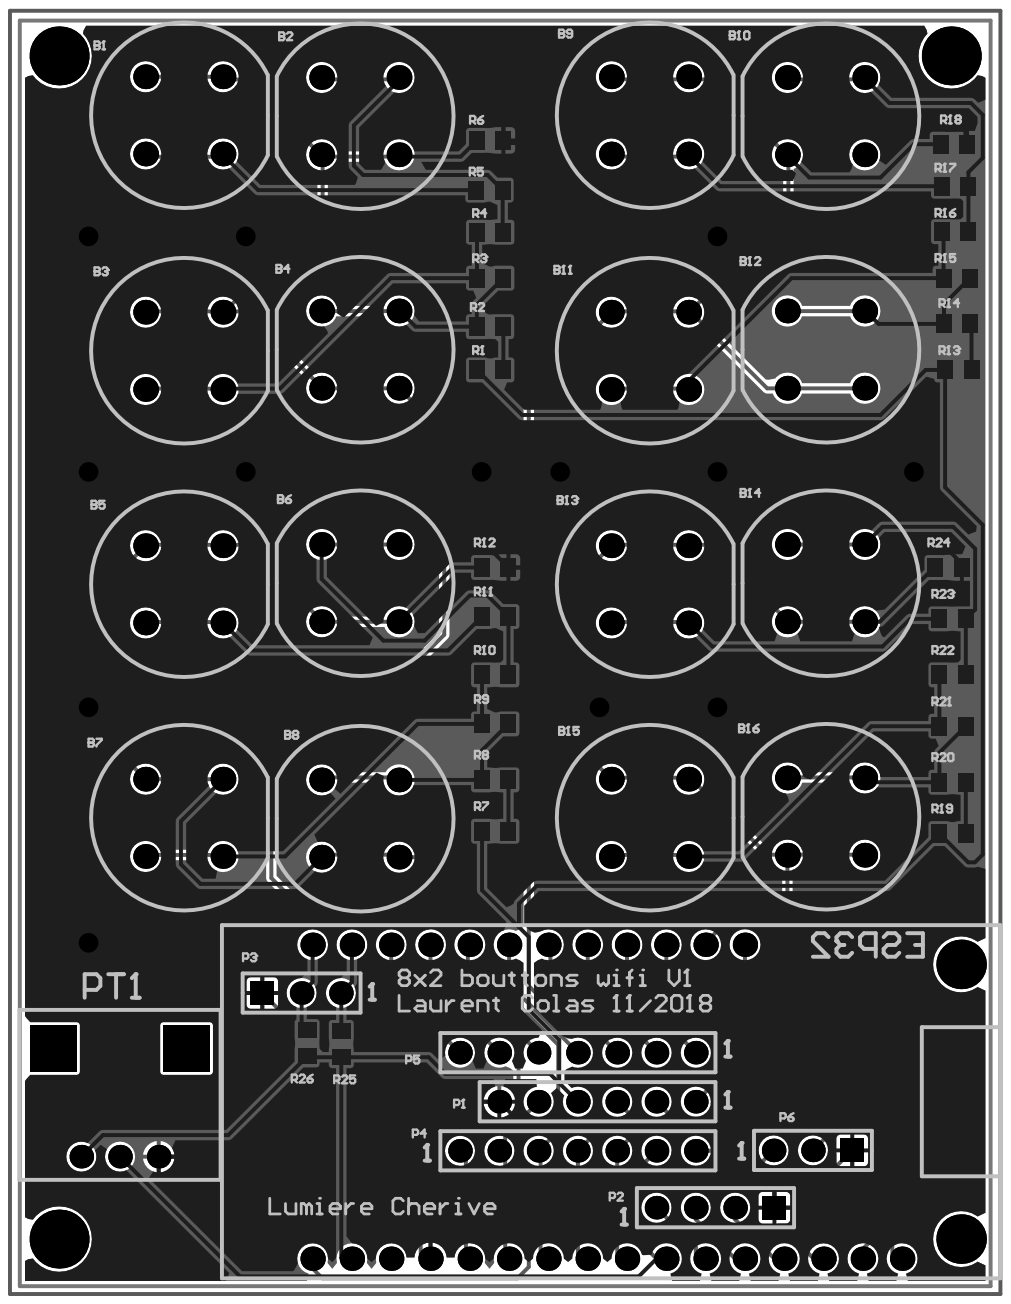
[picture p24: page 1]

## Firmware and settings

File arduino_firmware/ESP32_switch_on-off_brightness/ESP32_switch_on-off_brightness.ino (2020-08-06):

#include <esp_sleep.h>
#include <WiFi.h>
#include <WiFiClient.h>

//Pushbuttons connected to GPIO32 & GPIO33 & GPIO34 & GPIO35 & GPIO36 & GPIO39
#define BUTTON_PIN_BITMASK 0x9600000000 //0x700000000 //

typedef int32_t esp_err_t;
int GPIO_WAKE;
int period = 3000;
unsigned long time_now = 0;
RTC_DATA_ATTR int bootCount = 0;

const char* ssid = "LumiereColas";
const char* password =  "lumierecherive";
String complete_addresse;
const char* host = "192.168.2.41";
const int httpPort = 5000;

String code = "/SwitchDetector";
char* locations[] = {"SW1", "SW2", "SW3", "SW4","SW5", "SW6", "SW7", "SW8", "SW9",  "SW10"};
                     
int pin_maping[] = {34, 21, 39, 27, 36, 4, 33, 15, 35, 14};

unsigned long timeout;

int debug = 1;

WiFiClient client;

void print_GPIO_wake_up(){
  uint64_t GPIO_reason = esp_sleep_get_ext1_wakeup_status();
  Serial.println("GPIO that triggered the wake up: GPIO ");
  //Serial.println((log(GPIO_reason))/log(2), 0);
  GPIO_WAKE = (log(GPIO_reason))/log(2);
  Serial.println(GPIO_WAKE);
}

//Function that prints the reason by which ESP32 has been awaken from sleep
void print_wakeup_reason(){
  esp_sleep_wakeup_cause_t wakeup_reason;
  wakeup_reason = esp_sleep_get_wakeup_cause();
  switch(wakeup_reason)
  {
    case 1  : Serial.println("Wakeup caused by external signal using RTC_IO"); break;
    case 2  : Serial.println("Wakeup caused by external signal using RTC_CNTL"); break;
    case 3  : Serial.println("Wakeup caused by timer"); break;
    case 4  : Serial.println("Wakeup caused by touchpad"); break;
    case 5  : Serial.println("Wakeup caused by ULP program"); break;
    default : Serial.println("Wakeup was not caused by deep sleep"); break;
  }
  
  delay(100);
  
}


void setup() {
  // put your setup code here, to run once:
  Serial.begin(115200);
  delay(100); 
  Serial.println("Hello There");
  delay(100);
  
  touch_pad_intr_disable();
  
  //Increment boot number and print it every reboot
  ++bootCount;
  Serial.println("Boot number: " + String(bootCount));
  delay(1000);
  //Print the wakeup reason for ESP32
  print_wakeup_reason();

  //Print the GPIO used to wake up
  print_GPIO_wake_up();

  setup_IO();
  more_inputs();
  GPIO_WAKE = 0;
  //Configure GPIOxx as ext1 wake up source for HIGH logic level
  esp_sleep_enable_ext1_wakeup(BUTTON_PIN_BITMASK,ESP_EXT1_WAKEUP_ANY_HIGH);

  
  Serial.println("Going to sleep now");
  delay(100);

  //Go to sleep now
  esp_deep_sleep_start();
}

void loop() {}



void check_GPIO_states() {
    delay(1000);
}

void setup_IO(){
  pinMode(33, INPUT);
  pinMode(34,INPUT);
  pinMode(35, INPUT);
  pinMode(36, INPUT);
  pinMode(39, INPUT);
  pinMode(21,INPUT);
  pinMode(27, INPUT);
  pinMode(4, INPUT);
  pinMode(15, INPUT);
  pinMode(14, INPUT);
}

void more_inputs() {
  int pressed_button;
  int previous_pressed = 0;
  time_now = millis();
  Serial.println("Make your Move");
  delay(100);
  //pressed_button = read_buttons();
  while (millis() < time_now + period) {
    pressed_button = read_buttons();
    if (pressed_button > 0 || pressed_button != previous_pressed) {
      
      send_wifi_state(pressed_button);
      
      previous_pressed = pressed_button;
    }
    
    pressed_button = 0;
  }
}

int read_buttons(){
  int val = 0;
  if(digitalRead(33) == HIGH) {
    val = 33;
  }
  else if(digitalRead(34) == HIGH) {
    val = 34;
  }
  else if (digitalRead(34) == HIGH){
    val = 35;
  }
  else if (digitalRead(36) == HIGH){
    val = 36;
  }
  else if (digitalRead(39) == HIGH){
    val = 39;
  }
  else if (digitalRead(21) == HIGH){
    val = 21;
  }
  else if (digitalRead(27) == HIGH){
    val = 27;
  }
  else if (digitalRead(4) == HIGH){
    val = 4;
  }
  else if (digitalRead(15) == HIGH){
    val = 15;
  }
  else if (digitalRead(14) == HIGH){
    val = 14;
  }
  else {
    val = 0;
  }
  return val;
}

void send_wifi_state(int pressed_button) {
  int brightness = 0;
  int pressed_button_index = 0;
  brightness = potentiometerTranslate(analogRead(32));
  
  if (debug == 0) {
    ConnectToWiFi();
  }

  pressed_button_index = convert_pin_to_index(pressed_button);
  delay(100);
  Serial.print("pressed button index: " + pressed_button_index);
  complete_addresse= code + "?light=" + locations[pressed_button_index] +"&state=" + brightness;
  Serial.print("Requesting URL: ");
  Serial.println(complete_addresse);

  
  Serial.print("Send wifi of pin: ");
  Serial.print(pressed_button);
  Serial.print(" at intensity: ");
  Serial.println(brightness);

  if (debug == 0) {
    if (!client.connect(host, httpPort)) {
      Serial.println("connection failed");
      return;
    }
    client.print(String("GET ") + complete_addresse + " HTTP/1.1\r\n" +
                   "Host: " + host + "\r\n" +
                   "Connection: close\r\n\r\n");
  //  client.print(String("GET ") + complete_addresse + " HTTP/1.1\r\n");               
    unsigned long timeout = millis();
    while (client.available() == 0) {
        if (millis() - timeout > 5000) {
            Serial.println(">>> Client Timeout !");
            client.stop();
            return;
        }
  }
  
    // Read all the lines of the reply from server and print them to Serial
    while(client.available()) {
        String line = client.readStringUntil('\r');
        Serial.print(line);
    }
  
    Serial.println();
    Serial.println("closing connection");
    complete_addresse = "";
    }
  
}

int potentiometerTranslate(int PotRead) {

  return (PotRead * 100) / 4095;
}

int convert_pin_to_index(int pressed_button) {
  int i;
  int pressed_button_index;
  for (i=0;i<10;i++) {
    if (pin_maping[i] == pressed_button) {
      pressed_button_index = i;
    }
  }
  return pressed_button_index;
}


void ConnectToWiFi() {
  WiFi.begin(ssid, password);
  while (WiFi.status() != WL_CONNECTED) {
    delay(500);
    Serial.print(".");
  }
  
  Serial.println("Connected to the WiFi network");
  Serial.println("");
  Serial.println("WiFi connected");  
  Serial.println("IP address: ");
  Serial.println(WiFi.localIP());
  Serial.print("Netmask: ");
  Serial.println(WiFi.subnetMask());
  Serial.print("Gateway: ");
  Serial.println(WiFi.gatewayIP());
}

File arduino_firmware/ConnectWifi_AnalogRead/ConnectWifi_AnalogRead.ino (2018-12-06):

#include <WiFi.h>
#include <WifiClient.h>

#define ANALOG_PIN_1 25
#define ANALOG_PIN_2 34
#define ANALOG_PIN_3 39

int analog_value = 0;
int ButtonRead = 0;
int PressedButton = 0;
int PreviousPressedButton1 = 0;
int PreviousPressedButton2 = 0;
int PreviousPressedButton3 = 0;
int value = 0;
int state;

bool lastpressedbutton1 = true;
bool lastpressedbutton2 = true;
bool lastpressedbutton3 = true;
bool lastpressedbutton4 = true;
bool lastpressedbutton5 = true;
bool lastpressedbutton6 = true;
bool lastpressedbutton7 = true;
bool lastpressedbutton8 = true;

const char* ssid = "VIDEOTRON9664";
const char* password =  "ym8qxtb3cg";

String complete_addresse;
const char* host = "192.168.0.106";
const int httpPort = 8090;

String http_adresse = "http://";
String host_code = "192.168.0.106:8090";
String code = "/ButtonDetector";
char* locations[] = {"light1ON", "light1OFF","light2ON", "light2OFF","light3ON", "light3OFF","light4ON", "light4OFF"};
String location;

unsigned long timeout;

WiFiClient client;

void setup() {

  // put your setup code here, to run once:
  Serial.begin(115200);
  Serial.println("Connecting to WiFi..");
  
  WiFi.begin(ssid, password);
  while (WiFi.status() != WL_CONNECTED) {
    delay(500);
    Serial.print(".");
  }
  
  Serial.println("Connected to the WiFi network");
  Serial.println("");
  Serial.println("WiFi connected");  
  Serial.println("IP address: ");
  Serial.println(WiFi.localIP());
  Serial.print("Netmask: ");
  Serial.println(WiFi.subnetMask());
  Serial.print("Gateway: ");
  Serial.println(WiFi.gatewayIP());

  
}

void loop() {
  ButtonRead = analogRead(ANALOG_PIN_1);
  PreviousPressedButton1 = ReadButtonONOFF(0, ButtonRead, PreviousPressedButton1);  

  ButtonRead = analogRead(ANALOG_PIN_2);
  PreviousPressedButton2 = ReadButtonONOFF(4, ButtonRead, PreviousPressedButton2);

  ButtonRead = analogRead(ANALOG_PIN_3);
  PreviousPressedButton3 = ReadButtonONOFF(8, ButtonRead, PreviousPressedButton3);

  delay(1000);
}



void SendLightState(int PressedButton){
  state = PressedButton % 2;

  
  if (!client.connect(host, httpPort)) {
    Serial.println("connection failed");
    return;
  }
  
  complete_addresse= code + "?light=" + locations[PressedButton-1] + "&state=" + state;
  Serial.print("Requesting URL: ");
  Serial.println(complete_addresse);

  client.print(String("GET ") + complete_addresse + " HTTP/1.1\r\n" +
                 "Host: " + host + "\r\n" +
                 "Connection: close\r\n\r\n");
  unsigned long timeout = millis();
  while (client.available() == 0) {
      if (millis() - timeout > 5000) {
          Serial.println(">>> Client Timeout !");
          client.stop();
          return;
      }
  }
  
  // Read all the lines of the reply from server and print them to Serial
  while(client.available()) {
      String line = client.readStringUntil('\r');
      Serial.print(line);
  }

  Serial.println();
  Serial.println("closing connection");

  complete_addresse = "";
}

int ReadButton(int AnalogIn, int ButtonRead, int PreviousPressedButton) {
  // grab the PressedButton state of the remote-buttons
  if (ButtonRead > 450 && ButtonRead < 550) {
    PressedButton = 1 + AnalogIn;
    PrintDetectedButton(PressedButton);
    SendLightState(PressedButton);
  }
  if (ButtonRead > 550 && ButtonRead < 750) {
    PressedButton = 2 + AnalogIn;
    PrintDetectedButton(PressedButton);
    SendLightState(PressedButton);
  }
  if (ButtonRead > 750 && ButtonRead < 1000) {
    PressedButton = 3 + AnalogIn;
    PrintDetectedButton(PressedButton);
    SendLightState(PressedButton);
  }
  if (ButtonRead > 1000) {
    PressedButton = 4 + AnalogIn;
    PrintDetectedButton(PressedButton);
    SendLightState(PressedButton);
  }

  if(PressedButton == PreviousPressedButton){
    return PressedButton;
  }
  else{
    PreviousPressedButton = PressedButton;
  }
  
  return PreviousPressedButton;
}

void PrintWifiInfo(){
  Serial.println("Connected to the WiFi network");
  Serial.println("");
  Serial.println("WiFi connected");  
  Serial.println("IP address: ");
  Serial.println(WiFi.localIP());
  Serial.print("Netmask: ");
  Serial.println(WiFi.subnetMask());
  Serial.print("Gateway: ");
  Serial.println(WiFi.gatewayIP());
}

void PrintDetectedButton(int PressedButton){
    Serial.print("Analog ");
    Serial.print(PressedButton);
    Serial.print(" detected");
    Serial.println("");
}

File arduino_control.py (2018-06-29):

from flask import Flask, request

import RPi.GPIO as GPIO
import logging
from collections import defaultdict

import smbus
import time
import sys

import isodate

bus = smbus.SMBus(1)
# This is the address we setup in the Arduino Program
# Slave Address 1
address = 0x04
GPIO.setmode(GPIO.BCM)

app = Flask(__name__)

def write_number(value):
    bus.write_byte(address, value)
    # bus.write_byte(address_2, value)
    # bus.write_byte_data(address, 0, value)
    return -1


def read_number():
    # number = bus.read_byte(address)
    number = bus.read_byte_data(address, 1)
    return number


def string_to_bytes(val):
    ret_val = []
    for c in val:
        ret_val.append(ord(c))
    return ret_val




@app.route('/helloesp')
def helloHandler():
	return 'Hello ESP8266, from Flask'

@app.route('/MotionDetector')
def MotionHandler():
	light = request.args.get('light', default = '*', type = str)
	state = request.args.get('state', default = 2, type = int)
	print(light);
	print(state);
	# http://192.168.0.106/MotionDetector?light=livingroom&state=1

	locationDict = defaultdict(list)
	locationDict = {
		'fan': ['A01','A02'],
		'light': ['A03','A04']
	}

	targetPins = locationDict[light]
	for i in range(len(targetPins)):
		command = "%s %d" % (targetPins[i], state)
		data_list = list(string_to_bytes(command))
		for j in data_list :
			write_number(j)
			time.sleep(.1)
		time.sleep(0.5)

    	return 'Hello ESP8266, from Flask'

@app.route('/ButtonDetector')
def ButtonHandler():
        light = request.args.get('light', default = '*', type = str)
        state = request.args.get('state', default = 2, type = int)
        print(light);
        print(state);
        # http://192.168.0.106/MotionDetector?light=livingroom&state=1

        locationDict = defaultdict(list)
        locationDict = {
                'fan': ['A01','A02'],
                'light': ['A03','A04']
        }

        targetPins = locationDict[light]
        for i in range(len(targetPins)):
                command = "%s %d" % (targetPins[i], state)
                data_list = list(string_to_bytes(command))
                for j in data_list :
                        write_number(j)
                        time.sleep(.1)
                time.sleep(0.5)

        return 'Hello ESP8266, from Flask'


app.run(host='0.0.0.0', port= 8090)

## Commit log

2018-07-27 Done more work on it. added mutliple buttons, with state and adresse all together
2018-08-05 Big push for the website buttons and controls
2018-10-25 Added new firmware for ESP32, ESP8266
2018-11-07 CAD documentation
    [PTA1543-2010CIB103.stp]
2018-11-07 Now works on pi with this update
    [macro_list.csv]
2018-11-08 Altium button project
    [Adafruit HUZZAH32 ESP32 Feather.PcbDoc, Adafruit HUZZAH32 ESP32 Feather.PrjPcb, Adafruit HUZZAH32 ESP32 Feather.SchDoc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]
2018-11-09 Altium button pcb
    [ButtonsBrightness.PrjPcb, ButtonsBrightnessPCB.PcbDoc, Resistor470-0804.PcbLib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]
2018-12-06 big push
    [56_Magog electrique.xlsx, Adafruit HUZZAH32 ESP32 Feather.PcbDoc, Adafruit HUZZAH32 ESP32 Feather.PrjPcb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]
2019-01-09 Manette et driver ctrl push
    [ButtonsBrightnessPCB.PcbDoc, ButtonsBrightnesssPCB.PcbDoc, Librairie_ctrl_lumiere.PcbLib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]
2019-02-15 Firmware for motion detector and cad clean
    [AssemblyV2.SLDASM, BDv2.SLDPRT, Boite Detecteur V2.SLDPRT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]
2019-03-02 general imporvements and updates
    [ButtonsBrightness.PrjPcb, Lumiere_ctrl_altium.PrjPcb, button_brightness_esp32.SchDoc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]
2020-01-22 clean up
    [light_db.csv, macro_list.csv]
2020-01-22 New flask app architecture local and deployed
    [light_db.csv, macro_db.csv, switch_db.csv]
2020-01-22 remove old architecture
    [macro_list.csv]
